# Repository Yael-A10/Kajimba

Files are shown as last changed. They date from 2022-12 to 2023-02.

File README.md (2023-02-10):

# Kajimba Pump

## Installation

---

1. Install [MicroPython](https://micropython.org/) on the **Raspberry Pi Pico**: [*Instructions*](https://www.raspberrypi.com/documentation/microcontrollers/micropython.html)
2. Move all the python files from the [`Python` folder](https://github.com/Yael-A10/Kajimba/tree/main/Python) onto the **Raspberry Pi Pico**, including the `logs.txt` file. To do this:
    - Install [Thonny](https://thonny.org/)
    - Once it's installed open it and plug in the **Raspberry Pi Pico** to your computer
    - Select `Raspberry Pi Pico` as your device in the bottom right corner of the [Thonny](https://thonny.org/) software.
    - Next click `file>open` and select `This computer` as the device to open from. Then open all the files you want to upload to the **Raspberry Pi Pico**.
    - For each file click `file>Save as...` and select `Raspberry Pi Pico` as the device to save to.

If all was done correctly the program should start running as soon as the **Raspberry Pi Pico** is powered.

## User guide

---

1. In the `main.py` file, change/add `mosfet` and `flowSensor` pins depending on how many pump/flowSensor pairs you have. These are the default pins:

    ```python
    #define the pump and flow sensor pins:
    mosfet1 = 19
    flowSensor1 = 8
    ```

2. If you added more pump/flowSensor pairs, create a new `pair` variable with your new `mosfet` and `flowSensor` pins and add it to `pairList`. This is the default pair:

    ```python
    #create the pump and flow sensor pairs:
    pair1 = pumpSensorPairs(mosfet1, flowSensor1)

    #add the pairs into the pair list
    pairList = [pair1]
    ```

3. Change the `ml1` and `ml2` values depending on the values needed, these are the default values:

    ```python
    #variables
    ml1 = 285
    ml2 = 300
    ```

4. Change the `percentToStartSlowing` value to a value between 0 and 90. This variable represents the percentage of the bottle that is filled and the pump(s) will start slowing down after that percent is reached. This is the default value:

    ```python
    percentToStartSlowing = 75 #variable set between 0 and 90 that controls when the pump(s) start slowing down
    ```

Once the **Raspberry Pi Pico** is powered it will automatically run `main.py`. If the display is connected it will:

- Ask the user if they want to run a test (which will run the **pump(s)** for 10 seconds and test if the **flow sensor(s)** gets any output (10 ml))

    - If you want to run the test, hold down the button for 3 seconds.
    - If not, press the button once and it will skip the test.

If the display is not connected, it will skip this test and move on directly to the next part:

- To choose between the preset `ml1` and `ml2` amounts to fill:
    - Press the button once to choose `ml1`
    - Hold down the button for 3 seconds to choose `ml2`
- To run the pump(s) you have two options:
    - To run the pump(s) indefinately hold down the button for 3 seconds. Press it again to stop.
    - To run the pump(s) for the set amount of `ml`, press the button once. The pump(s) will slow down incrementally as the bottle gets filled.

    > Note that you can press the button again at anytime to make the pump(s) stop running.

When the display is connected, it will display the amount of times a bottle was filled during the session (top value) and the total amount of times a bottle was filled (bottom value):

```
Filled: ()
Total: ()
```

The total amount of times a bottle was filled is stored on `logs.txt`, you can edit this value if you want to edit/reset the total amount of bottles filled.

## KiCad

---

Here is the unpopulated **PCB**:
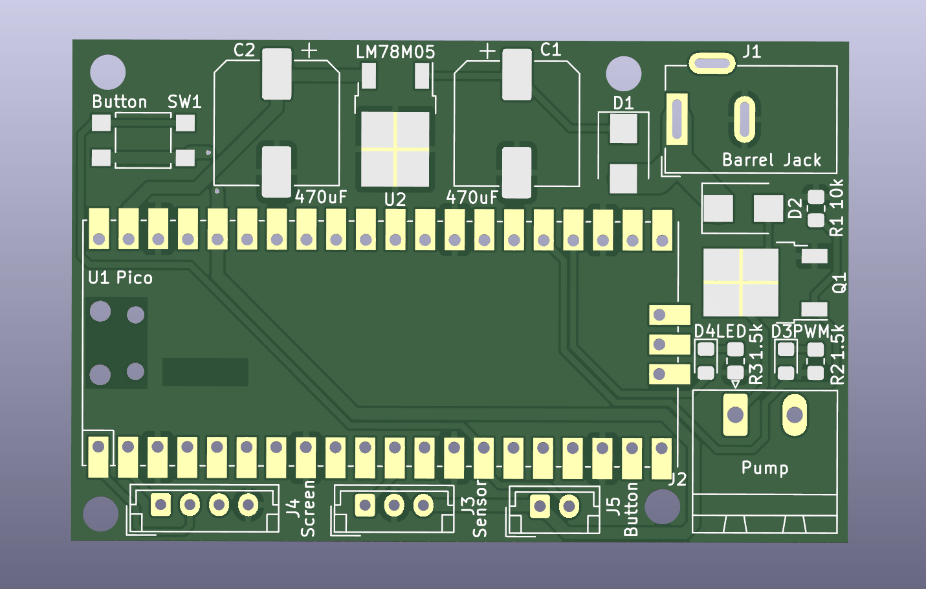
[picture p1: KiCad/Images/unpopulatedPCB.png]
Unpopulated PCB Image

Here is the populated **PCB**:
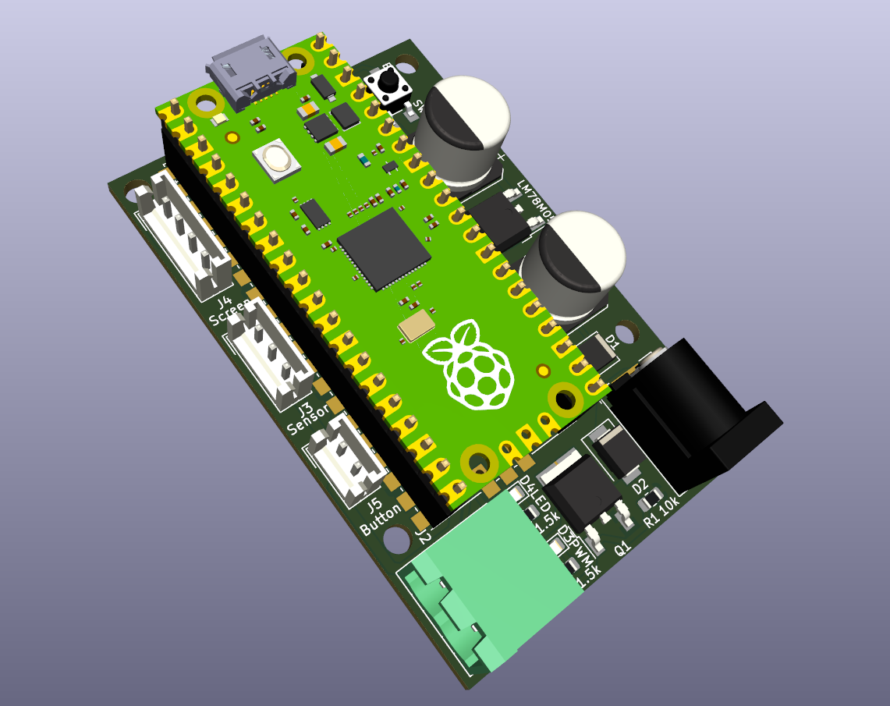
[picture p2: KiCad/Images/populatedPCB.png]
Populated PCB Image


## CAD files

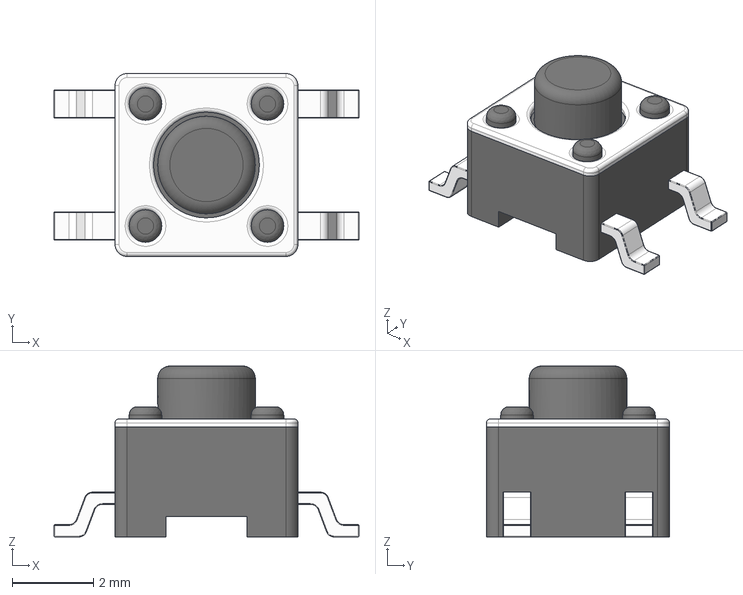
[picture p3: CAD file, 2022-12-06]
KiCad/Tact Switch 4.5mm SMT.step
7.50 x 4.50 x 4.20 mm

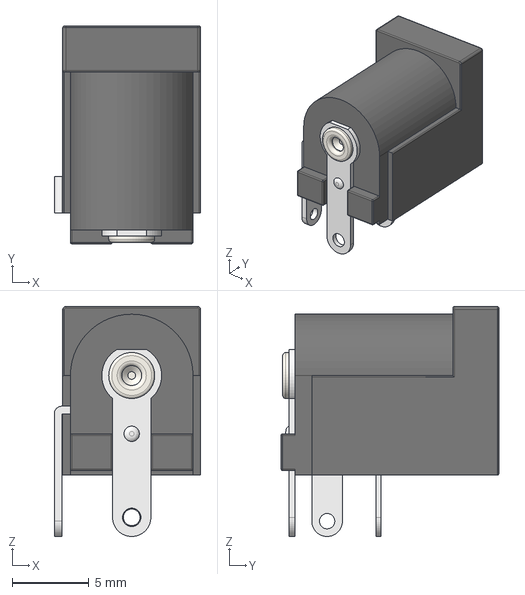
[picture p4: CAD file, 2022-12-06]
KiCad/DS-210.step
9.55 x 14.2 x 15.0 mm

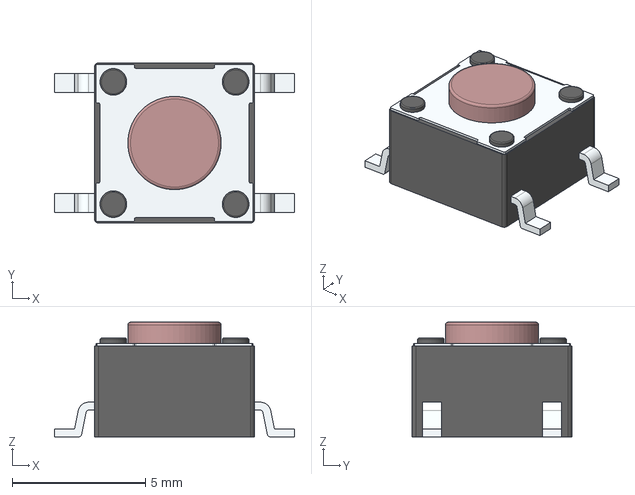
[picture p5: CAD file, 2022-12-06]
KiCad/SW-DTSM-61N-V.stp
9.00 x 6.00 x 4.30 mm

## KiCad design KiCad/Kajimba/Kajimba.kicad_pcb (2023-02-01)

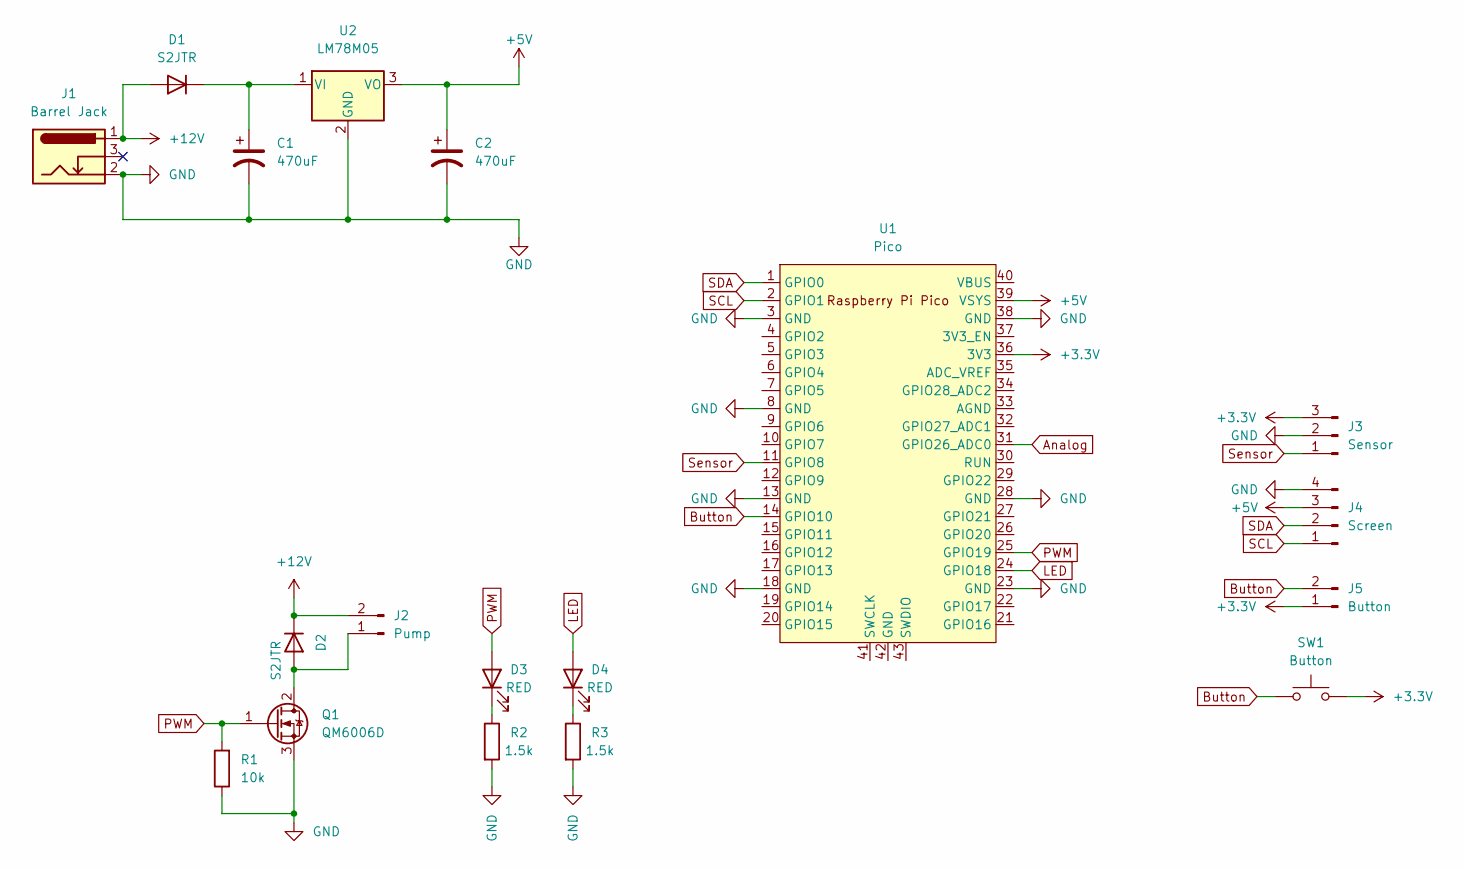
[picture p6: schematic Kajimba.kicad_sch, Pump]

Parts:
C1, C2: 470uF; CP_Elec_10x10.5
D1, D2: S2JTR; D_SMB
D3, D4: RED; LED_0805_2012Metric_Pad1.15x1.40mm_HandSolder
J1: Barrel Jack; BarrelJack_Wuerth_6941xx301002
J2: Pump; PhoenixContact_MSTBA_2,5_2-G-5,08_1x02_P5.08mm_Horizontal
J3: Sensor; JST_EH_B3B-EH-A_1x03_P2.50mm_Vertical
J4: Screen; JST_EH_B4B-EH-A_1x04_P2.50mm_Vertical
J5: Button; JST_EH_B2B-EH-A_1x02_P2.50mm_Vertical
Q1: QM6006D; TO-252-2
R1: 10k; R_0805_2012Metric_Pad1.20x1.40mm_HandSolder
R2, R3: 1.5k; R_0805_2012Metric_Pad1.20x1.40mm_HandSolder
SW1: Button; SW_SPST_TL3305A
U1: Pico; RPi_Pico_SMD_TH
U2: LM78M05; TO-252-2

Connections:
+3.3V: J3.3, J5.1, SW1.2, U1.36 (3V3)
+5V: C2.1, J4.3, U1.39 (VSYS), U2.3 (VO)
+12V: D1.2 (A), D2.1 (K), J1.1, J2.2
Analog: U1.31 (GPIO26_ADC0)
Button: J5.2, SW1.1, U1.14 (GPIO10)
GND: C1.2, C2.2, J1.2, J3.2, J4.4, Q1.3 (S), R1.1, R2.2, R3.2, U1.3 (GND), U1.8 (GND), U1.13 (GND), U1.18 (GND), U1.23 (GND), U1.28 (GND), U1.38 (GND), U2.2 (GND)
LED: D4.2 (A), U1.24 (GPIO18)
unnamed: C1.1, D1.1 (K), U2.1 (VI)
unnamed: D2.2 (A), J2.1, Q1.2 (D)
unnamed: D3.1 (K), R2.1
unnamed: D4.1 (K), R3.1
PWM: D3.2 (A), Q1.1 (G), R1.2, U1.25 (GPIO19)
SCL: J4.1, U1.2 (GPIO1)
SDA: J4.2, U1.1 (GPIO0)
Sensor: J3.1, U1.11 (GPIO8)

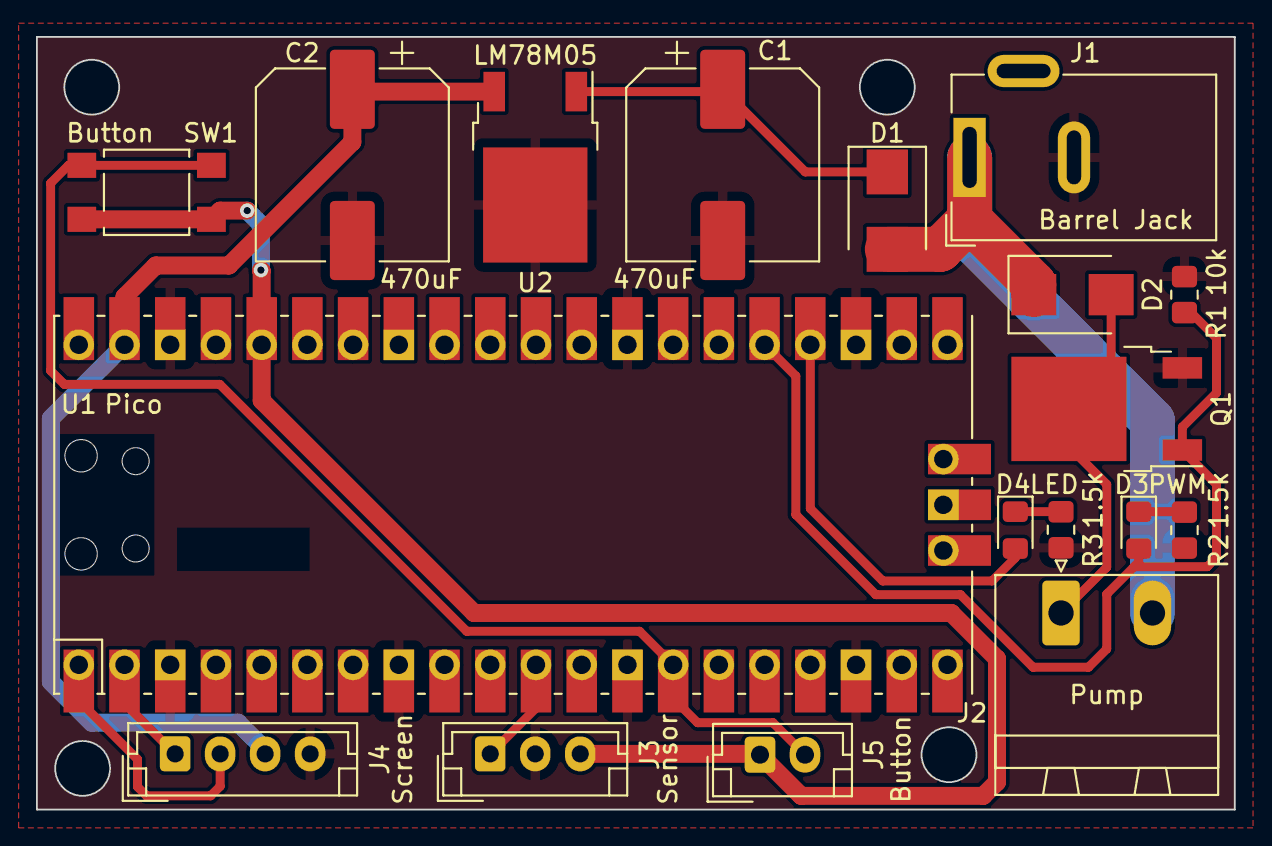
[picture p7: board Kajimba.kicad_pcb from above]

Board: 2 copper layers, 66.5 x 42.9 mm, 18 parts (0 on the bottom side), 14 nets.

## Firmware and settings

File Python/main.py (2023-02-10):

import time
import machine
from lcdManager import writeToScreen, display, clearDisplay
from pumpManager import pumpSensorPairs, runPumps, checkIfDone, resetValues, logClose, pumpsOff
from buttonManager import button, holdButton
from testManager import runTest

#setup

#variables
ml1 = 285
ml2 = 300
percentToStartSlowing = 75 #variable set between 0 and 90 that controls when the pump(s) start slowing down

#led built into the raspberry pi pico used as power indicator
onLED = machine.Pin(25, machine.Pin.OUT)
onLED.on() 

#define the pump and flow sensor pins:
mosfet1 = 19
flowSensor1 = 8

#create the pump and flow sensor pairs:
pair1 = pumpSensorPairs(mosfet1, flowSensor1)

#add the pairs into the pair list
pairList = [pair1]

pumpsOff()

def main() -> None:
    """Main fucntion that loops indefinately"""
    if button.value() == 1:
        if holdButton(time.time(), "start clearing"):
            runPumps(time.time())
        else:
            writeToScreen("Filling...", "Filled: 0/" + str(len(pairList)))
            checkIfDone()
            display()

def chooseML(ml1: int, ml2: int) -> int:
    """Function that allows the user to choose at the beginning of the session between ml1 and ml2"""
    writeToScreen("Click = mL1:{}".format(ml1), "Hold = mL2:{}".format(ml2))
    while button.value() == 0:
        pass
    if holdButton(time.time(), "select ml2:{}".format(ml2)):
        return ml2
    return ml1

try:
    runTest()
    ml = chooseML(ml1, ml2)
    display()
    while True:
        main()
except KeyboardInterrupt:
    pumpsOff()
    clearDisplay()
    onLED.off()
    logClose()

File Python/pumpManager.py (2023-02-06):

import time
from machine import PWM, Pin
from lcdManager import writeToScreen, display
from buttonManager import releaseButton, button

session_fill_count = 0

#opens logs.txt to be able to read the total number of times filled
log = open("logs.txt", "r")
total_fill_count = int(log.read())
log.close()

class pumpSensorPairs:
    """Class that defines the pump and flow sensor pairs and manages them"""

    def __init__(self, mosfet: int, flowSensor: int, count: int = 0, done: bool = False) -> None:
        """Function that initialises class variables"""
        #initialise mosfet variables
        self.mosfet = PWM(Pin(mosfet))
        self.mosfet.freq(100000) #sets the mosfet frequency to 100k hz
        self.mosfetPin = mosfet
        #initialise flow sensor variables
        self.flowSensor = Pin(flowSensor, Pin.IN, Pin.PULL_UP)
        self.flowSensor.irq(trigger = Pin.IRQ_RISING, handler = self.countPulse) #interrupt handler
        self.flowSensorPin = flowSensor
        #initialise other variables
        self.count = count
        self.done = done

    def pumpOn(self) -> None:
        """Switch pump on"""
        self.mosfet.duty_u16(65535)

    def pumpOff(self) -> None:
        """Switch pump off"""
        self.mosfet.duty_u16(0)

    def countPulse(self, none:None = None) -> None:
        """Function that counts the amount of times the flow sensor(s) trigger(s) using an interrupt handler"""
        self.count += 1

    def __str__(self) -> str:
        """Returns the pump and flow sensor pins"""
        return "This pump is on pin {} and has a flow sensor on pin {}.".format(self.mosfetPin, self.flowSensorPin)

def pumpsOn() -> None:
    """Function that switches on the pumps with a 0.5 s time delay so that the power supply doesn't get overloaded"""
    from main import pairList
    for pair in pairList:
        pair.pumpOn()
        time.sleep(0.5)

def pumpsOff() -> None:
    """Function that switches off the pumps"""
    from main import pairList
    for pair in pairList:
        pair.pumpOff()

def runPumps(start: int) -> None:
    """Function that runs the pump(s) for an indefinite amount of time and dispays the run time on the screen"""
    pumpsOn()
    writeToScreen("Clearing...", "Run time:")
    while button.value() == 0:
        writeToScreen("", "Run time: {}".format(time.time()-(start)) + "s")
    pumpsOff()
    releaseButton()
    display()

def writeToLog() -> None:
    """Function that writes the total number of fills to logs.txt"""
    log = open("logs.txt", "w")
    log.write(str(total_fill_count))
    log.close()

def logClose() -> None:
    """Function that closes logs.txt when stopping program incase that it is open"""
    log.close()

def slowPumps(pair: pumpSensorPairs, percentFilled: int, percentToStartSlowing: int) -> None:
    """Function that slows the pump(s) ater the bottle is (percentToStartSlowing)% full"""
    speed = int(65000-(25000*((percentFilled - percentToStartSlowing)/(100-percentToStartSlowing)))) #slow down the pump(s) as the bottle fills
    pair.mosfet.duty_u16(speed)

def checkIfDone() -> None:
    """Function that runs the pump(s) and stops when the flow sensor(s) has reached the desired ml amount"""
    from main import ml, pairList, percentToStartSlowing
    global session_fill_count
    global total_fill_count
    done = 0
    resetValues()
    pumpsOn()
    while done<len(pairList) and button.value() == 0:
        for pair in pairList:
            if not pair.done:
                percentFilled = round((pair.count/4/ml)*100)
                if percentFilled > percentToStartSlowing: #if the bottle is more than (percentToStartSlowing)% filled, then it will start slowing down the pump(s)
                    slowPumps(pair, percentFilled, percentToStartSlowing)
                writeToScreen("Filling... " + str(percentFilled) + "%", "")
                if pair.count/4 >= ml:
                    pair.pumpOff()
                    pair.done = True
                    done += 1
                    writeToScreen("", "Filled {}/{}".format(str(done), len(pairList)))
                    session_fill_count+=1
                    total_fill_count+=1
                    writeToLog()
    if done>=len(pairList):
        time.sleep(1) #give user enough time to read the display if all the bottles were filled
    pumpsOff()

def resetValues() -> None:
        """Function that switches the pump(s) off and resets the values of count and done"""
        from main import pairList
        for pair in pairList:
            pair.count = 0
            pair.done = False

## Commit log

2022-12-06 Create kicad.gitignore
    Created kicad.gitignore
2022-12-06 KiCad Pump PCB v01
    [Kajimba.kicad_pcb, Kajimba.kicad_sch]
2022-12-06 KiCad PCB Pump v01.1
    [Kajimba.kicad_pcb]
2022-12-06 KiCad PCB Pump v02
    [Kajimba.kicad_pcb, Kajimba.kicad_sch]
2022-12-06 KiCad PCB Pump v03
    [Kajimba.kicad_pcb, Kajimba.kicad_sch]
2022-12-06 KiCad PCB Pump v04
    [Kajimba.kicad_pcb, Kajimba.kicad_sch]
2022-12-06 3d models + python into folder
    [DS-210.step, Pico.skp, SW-DTSM-61N-V.stp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]
2022-12-06 New KiCad Folder
    [DS-210.step, Kajimba.kicad_pcb, Kajimba.kicad_sch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]
2022-12-06 KiCad Folder Update
    Added Kajimba Gerbers plus Kajimba Backup Folders and files from USB stick
    [Kajimba-B_Cu.gbr, Kajimba-B_Mask.gbr, Kajimba-B_Silkscreen.gbr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]
2022-12-06 main.py Cleanup
    -pumpGroup made into dictionary
    -separated main loop into functions
    -better variable naming
2022-12-22 v05
    moved pin 3.3v_en to 3.3v
    switched pins on 3 pin jst connector
    cleaned up circuit diagram sheet
    [Kajimba.kicad_pcb, Kajimba.kicad_sch]
2022-12-30 main.py update
    - Updated code for mosfet functionality
    - Updated the pins for button and flow sensor
2023-01-18 v06 KiCad
    removed pot
    moved button / IO around
    [Kajimba.kicad_pcb, Kajimba.kicad_sch]
2023-01-31 Python main.py update
    fixed button glitches
    cleaned up code
    added tester
    [main.py]
2023-02-01 major python update
    - divided code into different files
    - changed pumpGroups dictionary into pumpSensorPairs class
    - fixed .gitignore file
    - fixed python bugs
    [buttonManager.py, lcdManager.py, main.py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]
2023-02-01 minor changes to kicad files
    [Kajimba.kicad_pcb, Pico.skp, Test.kicad_pcb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]
2023-02-02 Python file update
    - removed unnecessary files
    - started using interrupt handler instead of old method
    - updated some functions to be more descriptive
    - added functionality to buttonManager.py (added holdButton function)
    - modified README.md
2023-02-05 python improvements
    improvements to the pumpManager:
    - added function to switch on pumps with time delay
    - added function to switch off all pumps
    - added feature that pumps only start slowing down after bottle is 75 percent full
2023-02-06 python changes
    added variable for when the pump(s) should start slowing down
